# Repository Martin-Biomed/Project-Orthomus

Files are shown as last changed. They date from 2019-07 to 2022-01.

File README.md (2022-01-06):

# Project Orthomus
 Software made for testing and control of Project Orthomus (including relevant libraries)

Project Orthomus was made for the purpose of providing people with muscular dystrophy with an additional means to complete an arm flexion/extension motion. The idea is that the user can press the "Up" or "Down" buttons to incrementally change the position of the arms. The first prototype functioned as a display model only, the design still had to be adapted to use on an actual person.

I apologise for the disorganised nature of this repository, I was brand new to GitHub when I created it. The documentation process was also lacking during this project due to time constraints, but enough data can be used from this repository to create the project again if need be. It was a very useful learning experience.

orthomus_hd



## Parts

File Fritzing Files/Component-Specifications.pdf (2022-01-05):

### LiPo Battery

Specifications:
- Capacity: 2650 mAh
- Voltage Rating: 3S = 11.4V
- Discharge Rating: 30C

Additional Calculations:
- Total Current Discharge Capacity: 30 x C = 30 x 2.65 Ah = 79.5 A (maximum)
- Battery Voltage: 3S = 3 (3.7V) = 11.1V

### Servo Motor: RobotStar SBRS-5314HTG 280° Digital Metal Gear

Specifications:
- Operating Voltage: 7.4-11.1 V
- Operating Speed: 0.18 sec/60° or 0.14 sec/60°
- Stall Torque: 32.4 kg.cm or 53.1 kg.cm
- Rotation Scope: 0-280°
- Weight: 81g
- Size: 43 x 32 x 32.5 mm
- Operating Frequency: 1520 us/333 Hz, 900-2100 us
- Approximate Current Draw Range (Forum): 4-8 A

### Power Supply Relay: SPDT Relay (30A)

Specifications
- 1 common terminal
- 1 Normally Open (NO) terminal
- 1 Normally Closed (NC) terminal
- Weight: 37g
- Size: 20 x 20 x 8 mm
- Operating Voltage: 4.75-5.25V
- Contact rate: 250 VAC, 30 VDC
- Switching Current rate: 30A

### Solenoid Relays: 5V 2-Channel Relay Module 10A

Specifications
- Two Straight Headers, each with:
- 1 common terminal
- 1 Normally Open (NO) terminal
- 1 Normally Closed (NC) terminal
- Size: 39 x 51 mm
- Operating Voltage: 5V
- Contact rate: 10A, 28 VDC

### Solenoids: 12 VDC Pull Push Solenoid (Adafruit)

Specifications
- Current Draw: 250mA
- Operating Voltage: 12V
- Weight: 144 g
- Size: 40 x 29 x 25 mm
- Starting Force: 6N (50% duty cycle)

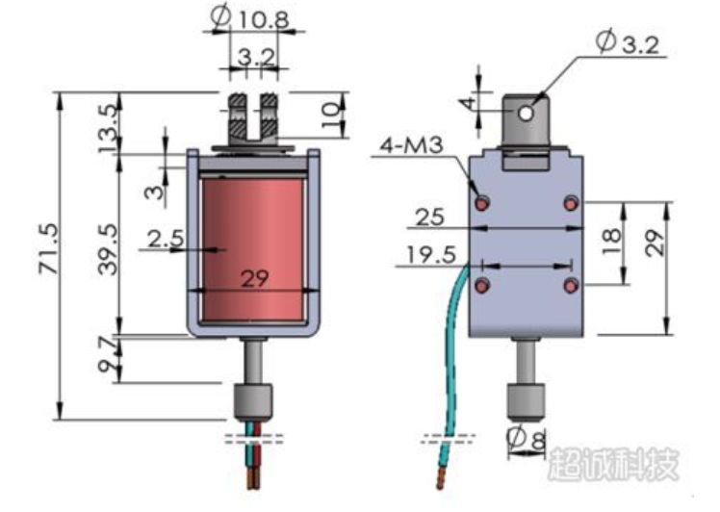
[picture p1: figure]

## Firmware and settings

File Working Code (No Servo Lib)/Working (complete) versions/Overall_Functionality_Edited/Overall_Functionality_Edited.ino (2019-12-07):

/* Buttons */
const int up_button = 5; //Normal Digital Pins
const int down_button = 6;
const int on_button = 3;

/* Relays */
const int main_power_relay = 9;
const int solenoid_relay_1 = 2;
const int solenoid_relay_2 = 7;

/* Servos */
const int servo_1 = 10; //PWM pins
const int servo_2 = 11;

/* Key variables */
int pwm1; // Variable that we send to the servos
int pwm2;
int deg; // The angular positions that we want servo to go to
int reverse_deg; // t

const int bottom_extreme = 15; //Extrema for device movement
const int top_extreme = 155;

#define extend1 digitalWrite(solenoid_relay_1, HIGH) //Defining the extension/retraction functions for both solenoids 
#define retract1 digitalWrite(solenoid_relay_1, LOW)
#define extend2 digitalWrite(solenoid_relay_2, HIGH)
#define retract2 digitalWrite(solenoid_relay_2, LOW)

bool up_button_state;
bool down_button_state;
bool on_button_state;
bool lock;
bool device_on;

void setup() {
    
    Serial.begin(9600);
    pinMode(up_button, INPUT);
    pinMode(down_button, INPUT);
    pinMode(on_button, INPUT);

    pinMode(main_power_relay, OUTPUT);
    pinMode(solenoid_relay_1, OUTPUT);
    pinMode(solenoid_relay_2, OUTPUT);
    
    reverse_deg = 180-bottom_extreme;
    lock = LOW; 
    device_on = LOW;
    
}

void loop() {
   
    main_power_control();
       
    device_movement_control();
    
 }

void main_power_control(){
   on_button_state = digitalRead(on_button); 
   if (on_button_state == HIGH && lock == LOW) {  //Buttons start off LOW until they are pressed
      lock = HIGH;                                //Once button has been pressed, lock = HIGH, meaning that this "if" statement is executed once until on_button is pressed again
      delay(20);
      pwm1 = map(deg, 0, 280, 116, 267);
      pwm2 = map(reverse_deg, 0, 280, 116, 267);
      analogWrite(servo_1, pwm1); //New lines supposed to turn off the servos before we start moving them
      analogWrite(servo_2, pwm2); 
        
  
      if (device_on == HIGH) {                    //If this loop is executed a second time, it means the on_button was hit again, at which point everything will be off
        Serial.println("Power supply is turned off");
        digitalWrite(main_power_relay, LOW);
        reset_procedure();
        extend1;
        extend2;
        device_on = LOW;
      }
      else {                                        //When the "if" statement is executed, runs through once, retracting the solenoids and enabling main power supply 
        Serial.println("Power supply is turned on");
        digitalWrite(main_power_relay, HIGH);
        retract1;
        retract2;
        device_on = HIGH;
      }
   }
   if (on_button_state == LOW && lock == HIGH) { //When the on_button is pushed again, lock = HIGH from the first turning on function
      lock = LOW;
   } 
}

void device_movement_control(){
   if (device_on == HIGH) {
       up_button_state = digitalRead(up_button);
       down_button_state = digitalRead(down_button);
       delay(30);
       
       if (up_button_state == HIGH) {
          retract1;                              //Retracting the solenoids in preparation for movement
          retract2;   
          Serial.println("Button up pressed");
          delay(300);
          up_button_loop();
       }
       if (down_button_state == HIGH) {
          retract1;                               //Retracting the solenoids in preparation for movement
          retract2;
          delay(300);
          Serial.println("Button down pressed");
          down_button_loop();
       }
   }
}
void reset_procedure(){
    while (deg>15){
        pwm1 = map(deg, 0, 280, 114, 267);
        pwm2 = map(reverse_deg, 0, 280, 114, 267);
        analogWrite(servo_1, pwm1);
        analogWrite(servo_2, pwm2);
        deg = deg - 10;
        reverse_deg = reverse_deg + 10;
        delay(100);   
    }
}

void up_button_loop() {
  while (up_button_state == HIGH && deg < top_extreme) {   //If the user keeps button pressed, the state will be LOW for that duration
    up_button_state = digitalRead(up_button);
    Serial.println("up 10 degrees: " + String(deg));
    pwm1 = map(deg, 0, 280, 114, 267);
    pwm2 = map(reverse_deg, 0, 280, 114, 267);
    analogWrite(servo_1, pwm1);
    analogWrite(servo_2, pwm2);
    deg = deg + 10;
    reverse_deg = reverse_deg - 10;
    delay(500);
  }
  extend1;                                  //Extend the solenoids once the movement concludes
  extend2;
  deg = deg - 10;
  reverse_deg = reverse_deg + 10;
}
void down_button_loop() {
  while (down_button_state == HIGH && deg > bottom_extreme) {
    down_button_state = digitalRead(down_button);
    Serial.println("down 10 degrees: " + String(deg));
    pwm1 = map(deg, 0, 280, 114, 267);
    pwm2 = map(reverse_deg, 0, 280, 114, 267);
    analogWrite(servo_1, pwm1);
    analogWrite(servo_2, pwm2);
    deg = deg - 10;
    reverse_deg = reverse_deg + 10;
    delay(500);
  }
  extend1;                                //Extend the solenoids once the movement concludes
  extend2;
  deg = deg + 10;
  reverse_deg = reverse_deg - 10;
}

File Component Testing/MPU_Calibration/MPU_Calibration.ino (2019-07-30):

#include <SparkFunMPU9250-DMP.h>

#define SAMPLING_FREQUENCY 15 //Hz, we start testing a relatively low value with a maximum possible value of 1000

MPU9250_DMP sensor;

float current_angle;
float adjusted_roll;
float velocity;
float time_taken=0;
float sampling_period_ms;

void setup() {
  // put your setup code here, to run once:
  Serial.begin(19200);
  if (sensor.begin() != INV_SUCCESS)
     {
        while (1)
        {
          Serial.println("Unable to communicate with MPU-9250");
          Serial.println("Check connections, and try again.");
          Serial.println();
          delay(5000);
        }
     }
      sensor.dmpBegin(DMP_FEATURE_6X_LP_QUAT | DMP_FEATURE_GYRO_CAL | DMP_FEATURE_SEND_CAL_GYRO, 40);
      sampling_period_ms = round(1000*(1.0/SAMPLING_FREQUENCY));
}

void loop() {
  // put your main code here, to run repeatedly:
   time_taken=millis();
   Get_Angle();
   Get_Velocity();
   Serial.println("Angular displacement: " + String(adjusted_roll) + " Time (ms): " + String(millis()));
   Serial.println("Angular velocity: " + String(velocity) + " degrees per second");
    while((millis()-time_taken)<(sampling_period_ms)){
         delay(1);          
    }
 }

float Get_Angle(void){
    float angle;
    if ( sensor.fifoAvailable() )
        {
        if ( sensor.dmpUpdateFifo() == INV_SUCCESS)
        {
          sensor.computeEulerAngles();
          angle = sensor.roll;
          if((angle)>180)
            {
             adjusted_roll=(angle)-360;
            }
          else if (angle<=180)
            {
             adjusted_roll=angle; // +/- 180 degrees
            }
        }
    }
}
float Get_Velocity(void){
    velocity=sensor.calcGyro(sensor.gx);
}
